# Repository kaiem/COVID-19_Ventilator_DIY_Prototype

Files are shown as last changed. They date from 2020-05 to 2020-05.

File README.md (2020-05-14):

# COVID-19_Ventilator_DIY_Prototype

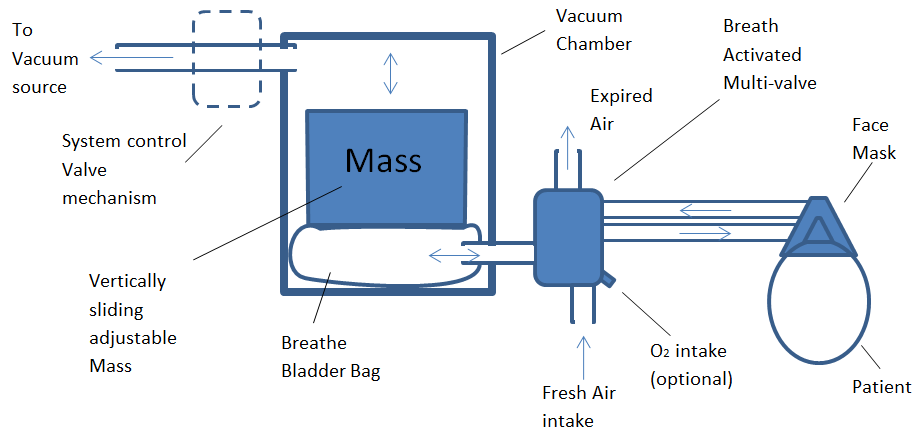
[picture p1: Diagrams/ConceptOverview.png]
Image of concept Optional Title


## Vacuum Powered Ventilator 
A COVID19 initiative, to create a prototype respirator/ventilator from basic household and 3D printed components, powered solely by a vacuum source such as a ducted vacuum system or household vacuum cleaner, and devoid of any electronic control apparatus.
[Watch Video](https://www.youtube.com/watch?v=GsDeOzsM8-c&feature=youtu.be)

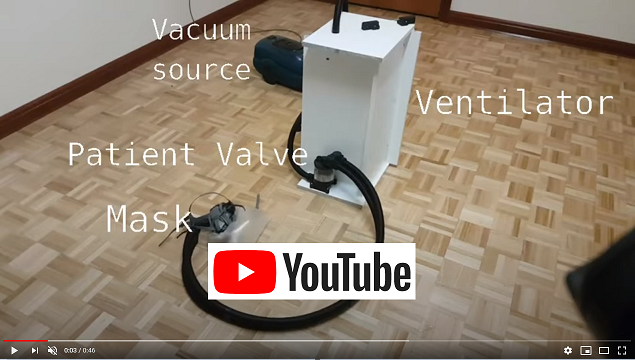
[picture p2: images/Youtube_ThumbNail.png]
IMAGE ALT TEXT HERE (https://www.youtube.com/watch?v=GsDeOzsM8-c&feature=youtu.be)


## *Project Status - Proof of concept, untested*

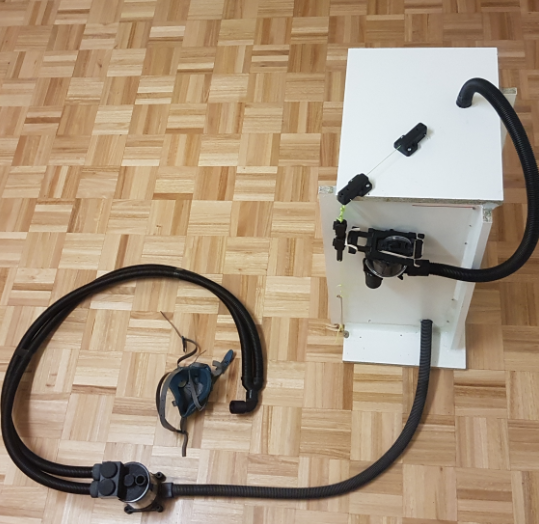
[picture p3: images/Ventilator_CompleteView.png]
Image of Ventilator Optional Title

.

## Aim - Establish a baseline for assessing feasibility
To establish a baseline for assessing the feasibility and suitability of a rudimentary low cost respirator/ventilator concept, as a possible aid in alleviating critical shortages of such equipment as being experienced in the medical industry resulting from the COVID19 pandemic.
Some of the discovered techniques, and ideas may provide benefit to unrelated applications.

## Motivation
At the rise of the pandemic, the dire prospect of severe triage denying access to hospital and ventilation equipment was felt. As a last resort option, attempts to purchase AMBU resuscitation bags failed with money being refunded due to shortage of supply. Invariably, open source projects attempting to fill the shortage of ventilators during the pandemic are based on automating the actuation of the basic AMBU resuscitation bag.

Without supply of AMBU resuscitations bags, is there an acceptable or at least a workable DIY fallback alternative?

## Objectives
- To perform the basic essential function of a medical respirator/ventilator – provide active cyclic aspiration and expiration of breathing air.
- To use only 3D printed plastic components and items obtained from household supermarket and hardware stores (readily available materials and items)
- To use benign materials - For materials in contact with breathing air supply
- To minimize the number of types of materials and items needing to be acquired
- To have low sensitivity to construction tolerances
- To provide provision for input of supplementary oxygen
- To be reliable
- To be adjustable
- To be serviceable
- To be simple to operate
- To be easily constructed
- To be devoid of any custom electronic or electrical components
- To eliminate reliance on electrical components and software
- To be low cost

## Requirements
- To deliver breathing air at a specific volume at a specific pressure followed by an adjustable duration for expiration, in a cyclic manner.
- The volume of air delivered (tidal volume) per breath cycle should be preset, adjustable and quantified.
- The pressure of air delivered in each breath cycle should be preset, adjustable and quantified.
- The duration for expiration per breath cycle should be easily adjustable.
- The energy required for operation should be supplied solely by a source of vacuum, such as from a ducted vacuum system or household vacuum cleaner.

## Challenges
- Creation of effective valve elements without the luxury of intricately molded silicon valve membranes, and/or precisely engineered metal spring components.
- Providing sealing without the luxury of precision dimensional tolerances for tight fitting self-sealing interconnecting components.
- Obtaining through household supply chains, items and materials used in transporting air which are benign or at least do not produce excessively hazardous or reactive emissions.
- Designing for safe failure modes.
- Providing sufficient usability without the use of intricate electronics and software.
- Providing effective means for monitoring of conditions and pressures without electronic sensing.

## Documentation
 - [Ventilator detailed documentation](https://github.com/kaiem/COVID-19_Ventilator_DIY_Prototype/blob/master/Doc)

## Build Files
- [BOM](https://github.com/kaiem/COVID-19_Ventilator_DIY_Prototype/blob/master/BOM)
- [STL](https://github.com/kaiem/COVID-19_Ventilator_DIY_Prototype/blob/master/STL)
- [GCODE](https://github.com/kaiem/COVID-19_Ventilator_DIY_Prototype/blob/master/gcode)

## Testing
Functional testing only has been performed. No testing whatsoever has been performed on human subjects.

## Conclusion
It was found that it is possible to create a rudimentary ventilator from readily available household items and 3D printed plastic components; however it is a much less trivial exercise than first expected. The challenges in not having access to high precision molded rubber-like flexible membrane parts for valving can be overcome albeit with an increase in complexity including a higher component count, and therefore reduced expected reliability. While the idea of using a weight on a bladder bag powered by an unregulated vacuum source in a separate air circuit was first thought and expected to give rise to an inherently safe system, in practice and after some FMEA analysis at least one potentially extreme adverse and hazardous condition was identified under component failure scenarios which could result in vacuum being transferred to the patient. Anyone embarking on utilizing this concept would be well advised to mitigate this outcome. Although the system looks simple, it is expected that a high level of familiarity, understanding and knowledge of the intricacies of this apparatus would be required in order to provide effective support to a patient, and as such may be deemed an un-user-friendly device. Additionally any non-ducted vacuum sources are typically particularly noisy, and would be best positioned in a separate room or enclosure.

## Further work
It is envisaged that another iteration of development would mitigate a critical safety issue identified, improve useablity as well as add an important mode for assisted breathing. Please refer to the relevant section in the [ventilator detailed documentation](https://github.com/kaiem/COVID-19_Ventilator_DIY_Prototype/blob/master/Doc).

Due to significant cost, time and effort involved, some fund raising is needed.

## Communication
Please provide suggestions and feedback by raising an issue or pull request.

## Sponsor or Contribute
A further iteration needs your support. Please donate or contribute. Your support will be much appreciated.

## References
Test Lung - https://medium.com/@RobertLeeRead/how-to-make-your-own-accurate-test-lungs-for-testing-emergency-ventilators-2d68fe5ac460

PEEP - https://derangedphysiology.com/main/cicm-primary-exam/required-reading/respiratory-system/Chapter%20508/methods-generating-positive

https://www.helpfulengineering.org/

https://techcrunch.com/2020/03/19/open-source-project-spins-up-3d-printed-ventilator-validation-prototype-in-just-one-week/

## Acknowledgements

https://www.instructables.com/id/The-Pandemic-Ventilator/

https://panvent.blogspot.com/2020/03/updated-bellows-style-pandemic.html

https://panvent.blogspot.com/2007/02/pandemic-ventilator-contingency.html

## Licensing
This work is licensed under Creative Commons Attribution-ShareAlike 4.0 International License.
- [(CC BY-SA 4.0)](https://creativecommons.org/licenses/by-sa/4.0/)

## Disclaimer
Presented here is a starting point for a proof of concept model, from which ideas or concepts disclosed are free for development and investigative purposes only.
No claims are made that any of the objectives or requirements as listed are desirable or if indeed they result in a solution which is suitable for human use, or if in fact the resulting prototype meets any objectives or requirements.
Anyone using this information agrees to waive any and all liability.

## Warning
A ventilator can be a hazardous device and requires appropriately medically trained and certified personnel.
This is an unproven, untested prototype with much more work required to make this device useable or acceptable for use.

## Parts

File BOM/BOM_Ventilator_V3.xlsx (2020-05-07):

Item | Description | Note | Catalogue Description & Brand | Source | Code | Price | Qtty | Length | Cost
1 | 3D Filament ABS |  | ESUN ABS, 1.75mm, 1Kg | Kingdom 3D |  |  |  |  | 0
2 | PVC Pipe 65mm DWV | 55mm in length required | Holman 65mm x 1m PVC DWV Pipe | Bunnings | I/N: 4770088 | $10.98 | 1 |  | 10.98
3 | PVC Pipe 90mm Storm water | 75mm in length required Option 1: Preferably use clear straight section from a clear Soft drink bottle**. Option 2: Build by 3D printing | Holman 90mm x 1m Stormwater Pipe | Bunnings | I/N: 4770093 | $8.70 | 0 |  | 0
4 | Polyethylene Hose flexible tubing |  | Aqua Systems 22mm x 10m Grey Water Diverter Hose Polyethylene Hose / Thermoplastic Rubber Couplings | Bunnings | I/N: 3110319 | $9.97 | 1 | 10 | 9.97
5 | PVC clear Tubing 5mm |  | Pope 5mm Clear Vinyl Tubing - 5m | Bunnings | I/N: 3130558 | $8.66 | 1 |  | 8.66
6 | Malemine board |  | Trade Essentials 1200 x 295mm 16mm ABS White Melamine | Bunnings | I/N: 0570548 | $9.05 | 3 |  | 27.15
7 | Timber strip 2"x1" 600mm |  | 42 x 19mm 1.2m Standard Grade Dressed Pine | Bunnings | I/N: 8401487 | $4.00 | 2 |  | 8
8 | String |  | Spear & Jackson 50m No8 Lime Green Brickline | Bunnings | I/N: 5830002 | $5.00 | 1 |  | 5
9 | Screws |  | Zenith 6G x 30mm Zinc Plated Hinge-Long Threads Countersunk Head Timber Screws - 35 Pack | Bunnings | I/N: 2420068 | $3.98 | 1 |  | 3.98
10 | Screws |  | Zenith 8G x 30mm Zinc Plated Self Tapper Pan Head Screws - 25 Pack | Bunnings | I/N: 2420152 | $3.98 | 1 |  | 3.98
11 | Screws |  | Zenith 8G x 25mm Zinc Plated Self Tapper Pan Head Sheet Metal Screws - 30 Pack | Bunnings | I/N: 2420148 | $3.98 | 1 |  | 3.98
12 | Nail 2.0mm |  | Paslode 50 x 2.0mm 100g Bright Steel Bullet Head Nails - 70 Pack | Bunnings | I/N: 2360382 | $3.98 | 1 |  | 3.98
13 | Bucket 5L |  | Handy Pail 5L Handy Pail | Bunnings | I/N: 4475883 | $6.49 | 2 |  | 12.98
14 | Duct Tape |  | Bear 48mm x 30m Black PVC Duct Tape | Bunnings | I/N: 1661581 | $5.85 | 1 |  | 5.85
15 | PVC Tape, 18mm Electrical |  | Nitto Denko 18mm x 20m Black PVC Electrical Insulation Tape | Bunnings | I/N: 4430715 | $2.90 | 1 |  | 2.9
16 | Nut M8 |  | Pinnacle M8 Stainless Steel Nylon Lock Nut - 6 Pack | Bunnings | I/N: 1100811 | $3.70 | 1 |  | 3.7
17 | Wood Glue |  | Selleys 100ml Aquadhere Interior Adhesive | Bunnings | I/N: 1230622 | $6.45 | 1 |  | 6.45
18 | Silione sealant (Neutral Cure) |  | Parfix 300g Clear All Purpose Silicone | Bunnings | I/N: 1232674 | $6.68 | 2 |  | 13.36
19 | 3M Face Mask |  | 3M Paint Project Reusable Respirators | Bunnings | I/N: 5820584 | $59.90 | 1 |  | 59.9
20 | Ziplock Plactic bag |  | Hercules resealable bag, Large, Twin Zip Storage Bags- 27 x33cm | Coles |  |  | 2 |  | 0
21 | Rubber bands |  |  | Coles |  |  | 3 |  | 0
22 | **Schweppes Solo Bottle 1.25 Litre (Optional) |  |  | Coles |  |  |  |  | 0
Tools |  |  |  |  |  |  |  |  | 0
 | 3D Printer | RepRap Perusa or equi- Build plate - 200mmx200mm |  |  |  |  |  |  | 0
 | Electric Saw (Timber) |  |  |  |  |  |  |  | 0
 | Extendable knife |  | Craftright 18mm Snap Off Knife With 5 Blades | Bunnings | I/N: 5760267 | $8.98 |  |  | 0
 | Cordless Drill (Any) |  |  | Bunnings |  |  |  |  | 0
 | Drill bit, 6.5mm, 2.5mm, |  |  | Bunnings |  |  |  |  | 0
 | Drill Spade bit, 28mm |  |  | Bunnings |  |  |  |  | 0
 | Plier Side Cutters |  |  | Bunnings
 | Scissors |  | Trojan 2 Piece Scissors Set | Bunnings | I/N: 6010594 | $7.98 |  |  | 0
Vacuum Options |  |  |  |  |  |  |  |  | 0
 | Vacuum (Options) | Noisy, very powerful | Ozito 1250W 12L Stainless Wet And Dry Vacuum | Bunnings | I/N: 6290589 | $49.98 |  |  | 0
 |  | Quiete but expensive | Miele S2121 Olympus |  |  |  |  |  | 0
 |  |  | Electrolux Silent Performer Eco-Friendly Bagless Vacuum |  |  |  |  |  | 0
 |  |  | Electrolux UltraSilencer EL6986A Canister Vacuum |  |  |  |  |  | 0
 |  |  | Electrolux Sanitaire SC3700A Quiet Clean Canister Vacuum. |  |  |  |  |  | 0
 |  |  | Hoover Commercial CH50400 Hush Tone Lite Upright Vacuum. |  |  |  |  |  | 0
 |  |  | Eureka EasyClean Corded 71B Hand-Held Vacuum |  |  |  |  |  | 0
 |  |  |  |  |  |  |  |  | 190.82

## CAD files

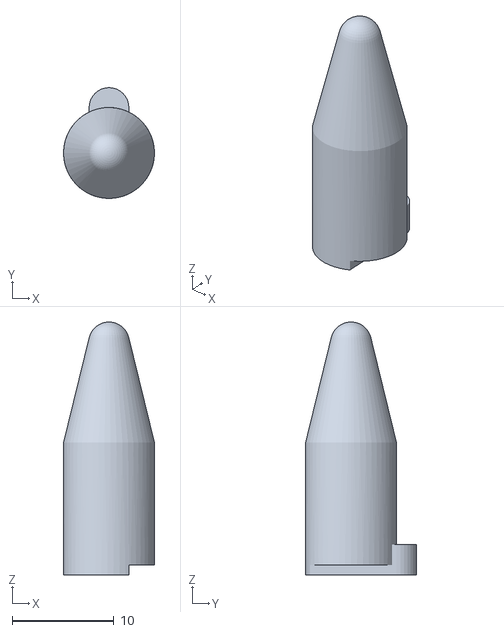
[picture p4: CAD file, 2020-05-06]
STL/BreathActivatedMultiValve/MainValve_ExhaustRod.stl
8.92 x 10.9 x 24.8

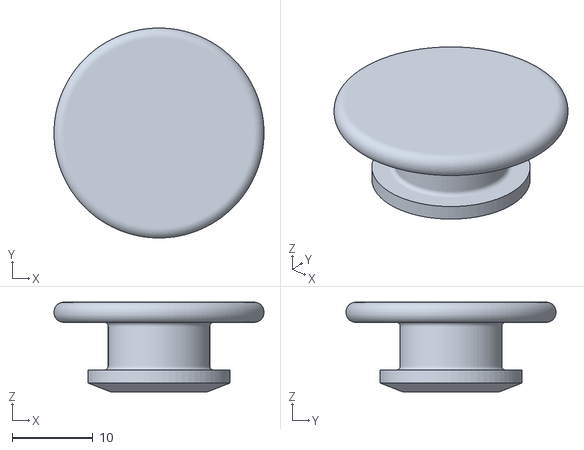
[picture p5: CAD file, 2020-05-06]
STL/BreathActivatedMultiValve/MainValve_ExhaustDisk.stl
26.0 x 26.0 x 11.1

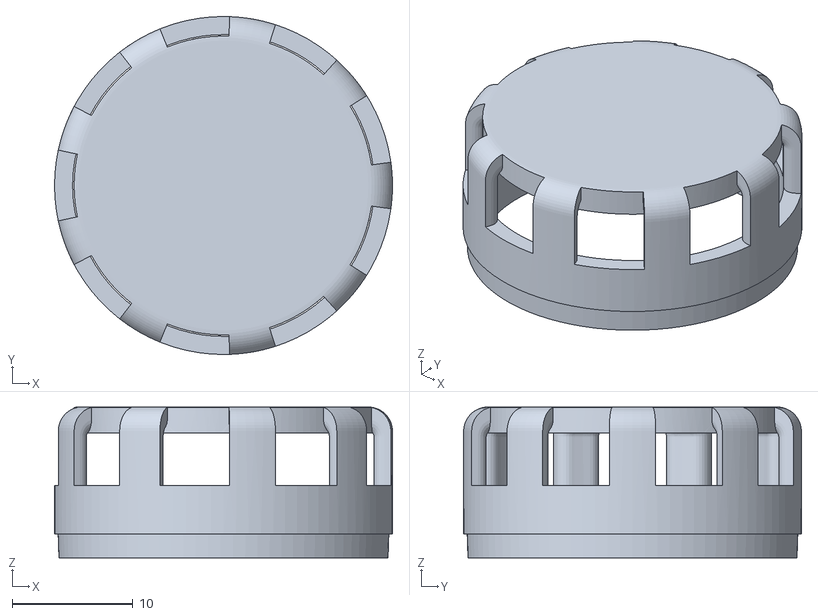
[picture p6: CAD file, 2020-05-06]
STL/BreathActivatedMultiValve/MainValve_IntakeCover.stl
28.0 x 28.0 x 12.5

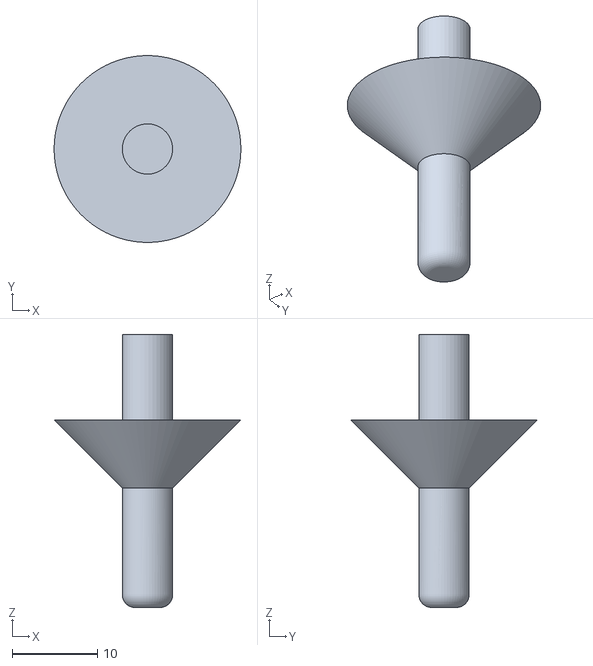
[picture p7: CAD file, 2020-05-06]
STL/BreathActivatedMultiValve/MainValve_PartD.stl
21.9 x 21.9 x 32.0

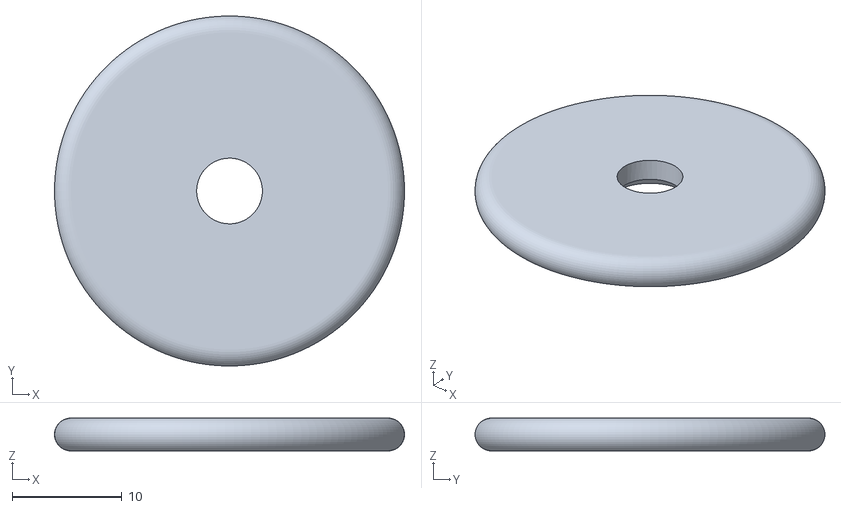
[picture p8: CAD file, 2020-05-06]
STL/BreathActivatedMultiValve/MainValve_PartC.stl
31.9 x 31.9 x 3.00

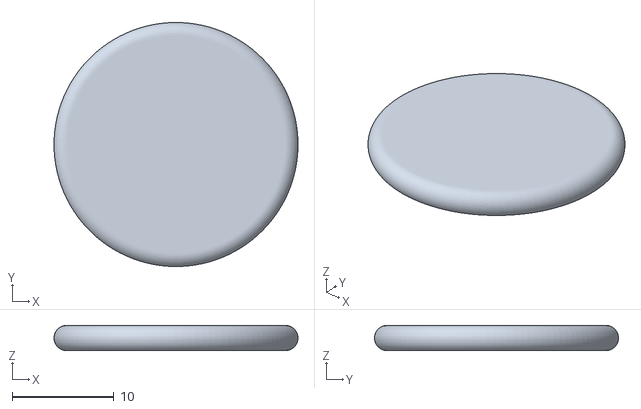
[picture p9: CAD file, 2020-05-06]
STL/BreathActivatedMultiValve/BreathTube_ValveDisk.stl
24.0 x 24.0 x 2.50

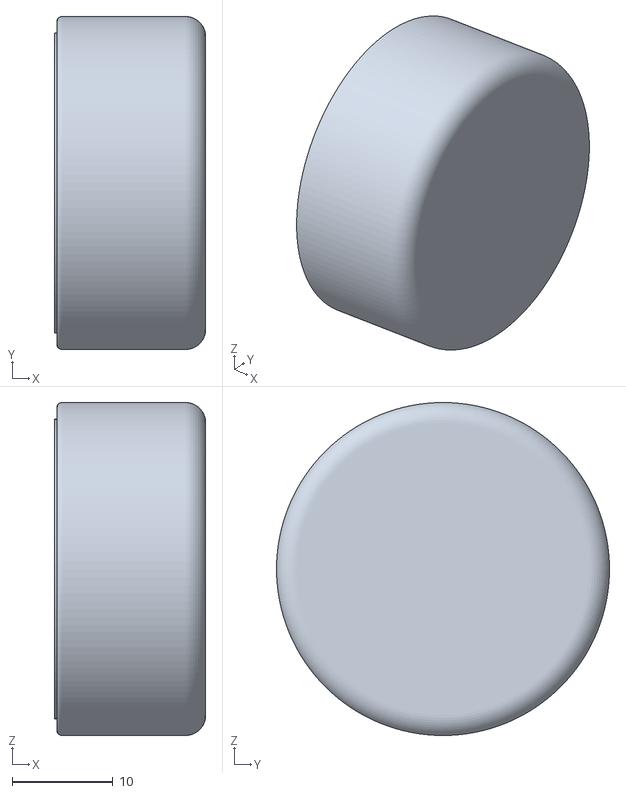
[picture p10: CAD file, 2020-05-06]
STL/BreathingTube&Mask/Plug_3M_Mask.stl
15.0 x 33.0 x 33.0

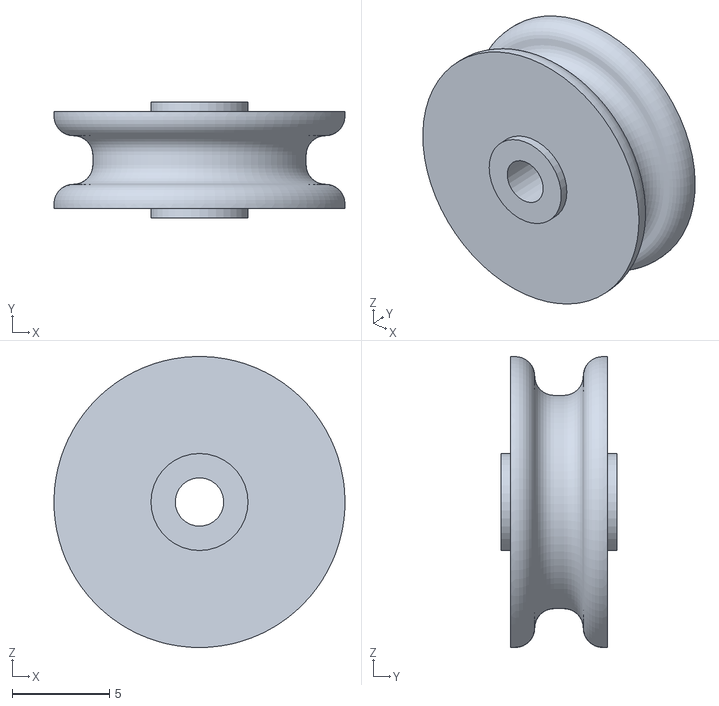
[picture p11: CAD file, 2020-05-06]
STL/SenseCordComponents/Pulley.stl
15.0 x 6.00 x 15.0

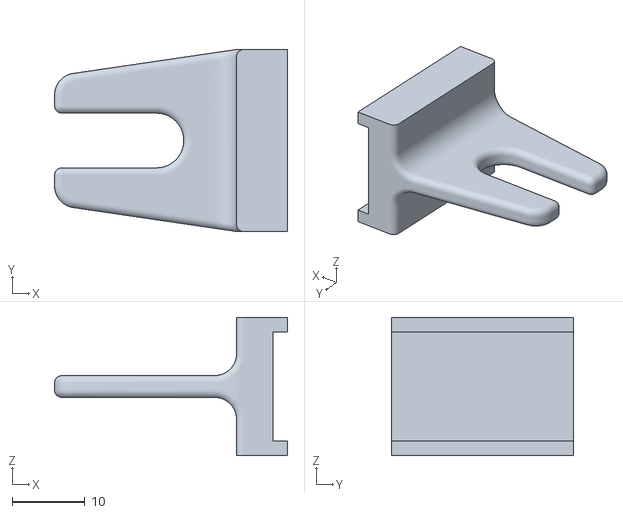
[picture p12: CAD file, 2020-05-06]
STL/SystemControlValveMech/VacValve_ToggleBreakAway.stl
32.0 x 25.0 x 19.0

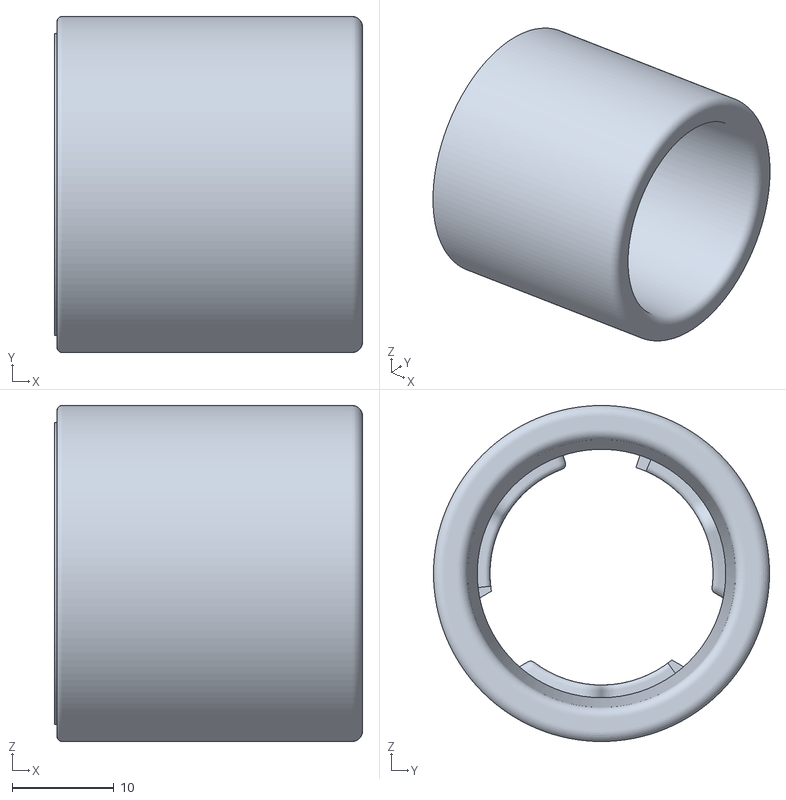
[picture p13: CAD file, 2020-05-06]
STL/BreathingTube&Mask/MaskAdaptor_3M.stl
30.2 x 33.0 x 33.0

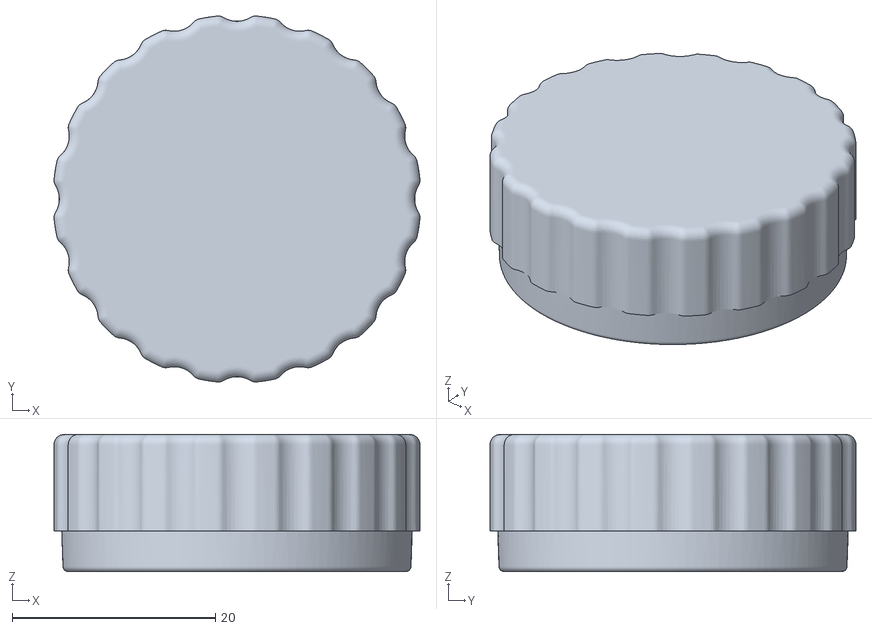
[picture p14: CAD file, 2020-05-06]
STL/SendReceiveValve/BreathTube_VaveCover.stl
36.0 x 36.0 x 13.5

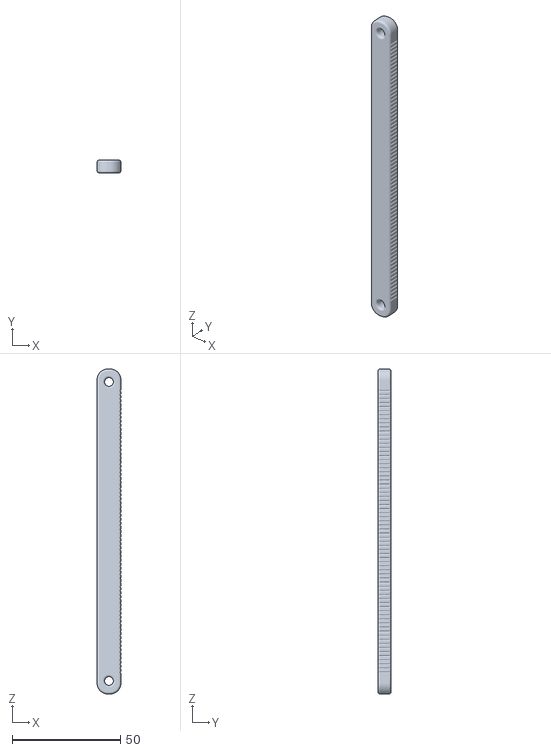
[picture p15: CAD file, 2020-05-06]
STL/SenseCordComponents/SliderLocatorStrip.stl
11.0 x 6.00 x 150.0

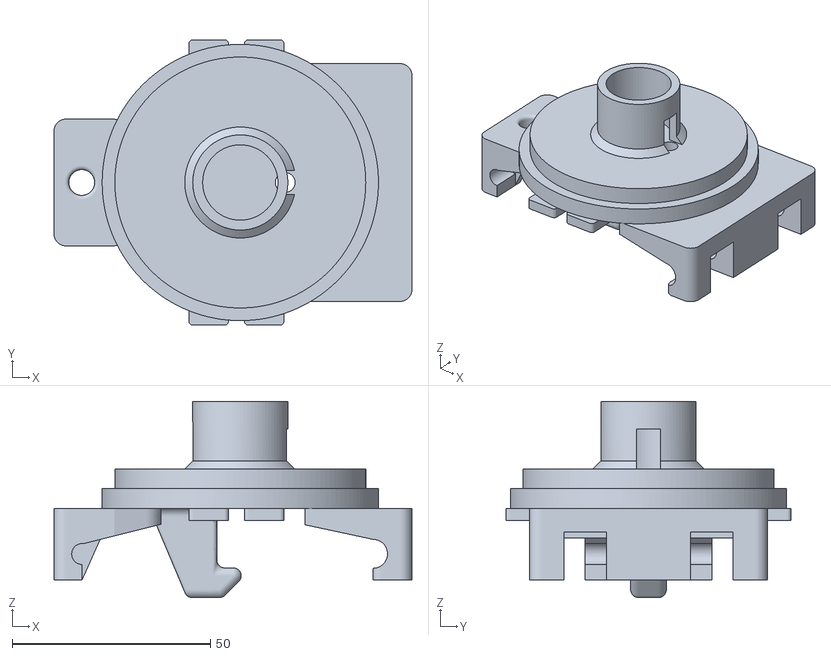
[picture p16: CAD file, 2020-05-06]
STL/SystemControlValveMech/VacValve_Bottom.stl
90.3 x 72.0 x 49.5

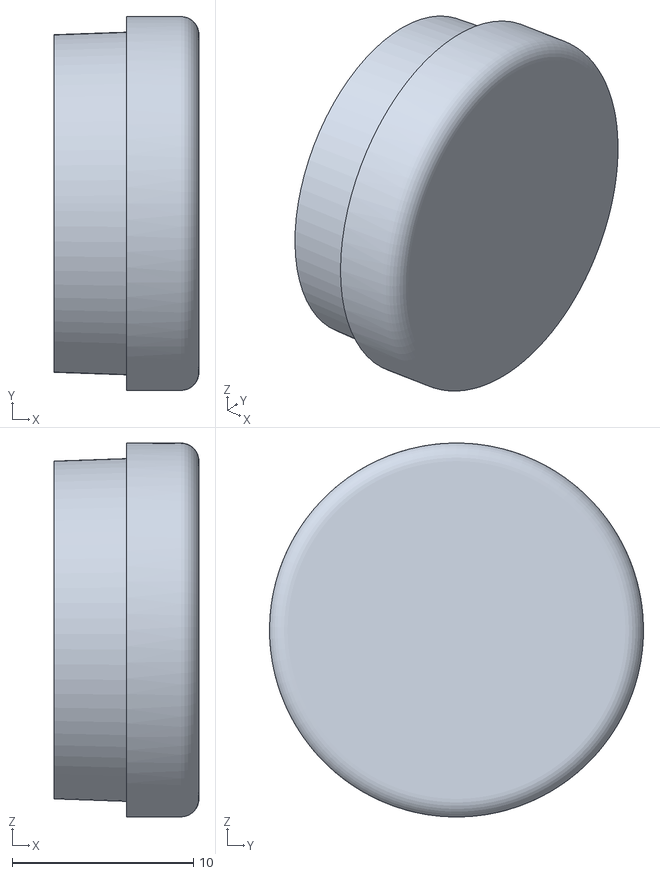
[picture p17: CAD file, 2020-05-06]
STL/SendReceiveValve/BreathTube_Plug.stl
8.00 x 20.6 x 20.6

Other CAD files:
STL/SenseCordComponents/StringLocatorAdjust_LockLevers.stl
STL/SystemControlValveMech/VacValve_SpeedDial.stl
STL/SenseCordComponents/SliderLocatorAdjust.stl
STL/BreathActivatedMultiValve/Ring_PlasticDiaphramRetainer.stl
STL/SystemControlValveMech/VacValve_DiaphramSheildRing.stl
STL/SystemControlValveMech/VacValve_OverCentre.stl
STL/SystemControlValveMech/VacValve_VacuumAttach.stl
STL/SystemControlValveMech/VacValve_ValvePtB.stl
STL/SystemControlValveMech/Vac_Valve_ToggleLever.stl

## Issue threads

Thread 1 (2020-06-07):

Chamber is too large

kaiem, 2020-06-07:
As is, the chamber needs only to be less than half the height.

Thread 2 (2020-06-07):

Sense chord makes opening chamber to adjust pressure cumbersome

kaiem, 2020-06-07:
A solid rod could be used to communicate position to the control valve instead of a chord.

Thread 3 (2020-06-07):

Vacuum adjust knob not sturdy

kaiem, 2020-06-07:
The knob used to adjust the vacuum (and effectively control the breathing rate), can fail. The shaft  is easily broken when 3D printed especially at low density.

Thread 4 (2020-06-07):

Reliable operation overly sensitive to pilot tube position

kaiem, 2020-06-07:
The system control valve toggle mechanism connects and disconnects the pilot tube from the cylinder control port, however the mating of the pilot tube to the receiving port is offset with respect to the radius of trajectory. As a result, reliable operation is overly sensitive to the assembled position of the pilot tube.

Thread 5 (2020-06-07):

Breath rate adjustment too sensitive

kaiem, 2020-06-07:
In the current topology, adjustment of the breath rate is achieved by turning the control knob which changes the rate of vacuum bleed. Reducing the supply vacuum too much in this way increases sensitivity to pilot tube positioning and thereby reduces reliability.

kaiem, 2020-06-07:
Suggest changing from bleed control to inline throttle in the output tube of the System Control Valve.

kaiem, 2020-06-07:
Suggest adding a vacuum regulator in the source vacuum line to control the supply vacuum to a known value which would enable the rate adjustment knob position to be consistent and able to be calibrated against breathing rate.

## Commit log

2020-05-14 Add files via upload
    Show TxRx tubing
2020-05-14 Add files via upload
    Add TxRx tubing
